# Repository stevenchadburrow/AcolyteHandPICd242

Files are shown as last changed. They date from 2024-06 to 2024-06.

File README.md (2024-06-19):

# AcolyteHandPICd242

This is the Acolyte Hand PIC'd 242, containing two PIC24 microcontrollers:  
The PIC24EP512GP202 and the PIC24FJ128GB202.  
The 'EP does all of the graphics, sound, and button inputs.  
The 'FJ is exclusively designed to be used as a USB host for HID and MSD.

The board is an all through-hole design for easy soldering.

Much of the code will be reused from the Acolyte Hand PIC'd 24 project.

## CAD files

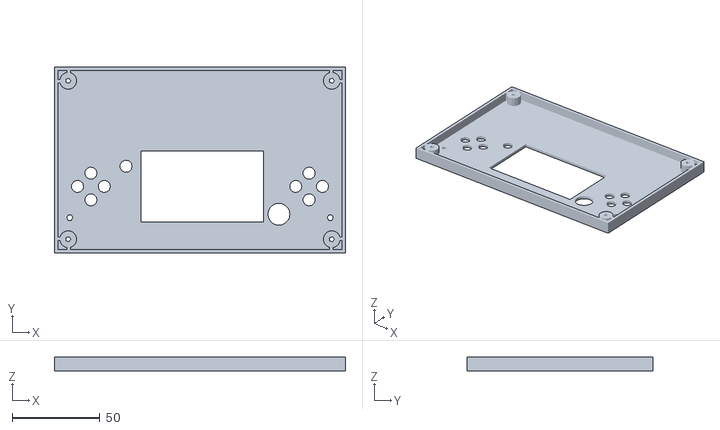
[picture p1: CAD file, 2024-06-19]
HandPICd242-BoxTop.stl
166.0 x 106.0 x 8.00

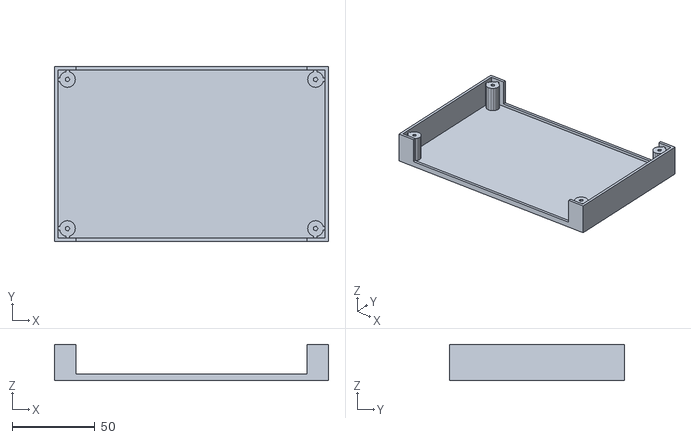
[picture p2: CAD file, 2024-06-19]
HandPICd242-BoxBottom.stl
166.0 x 106.0 x 22.0

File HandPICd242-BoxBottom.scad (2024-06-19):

width = 160;
depth = 100;
tall = 20;
short = 6;
holes = 4.825;

/*
// TOP HALF
translate([0, 0, 0]) {

// bottom
translate([-3, -3, -2]) {
    difference() {
        cube([width+6, depth+6, 2], center = false);
        translate([3+holes, 3+holes, -1]) {
            cylinder(4, 3, 3);
        }
        translate([3+width-holes, 3+holes, -1]) {
            cylinder(4, 3, 3);
        }
        translate([3+width-holes, 3+depth-holes, -1]) {
            cylinder(4, 3, 3);
        }
        translate([3+holes, 3+depth-holes, -1]) {
            cylinder(4, 3, 3);
        }
        translate([3, 3, 0]) {
            translate([46.355,14.605,-1]) {
                cube([70,40.64,4], center = false);
            }
            
            translate([17.78, 27.25, -1]) {
                cylinder(4, 3.5, 3.5);
            }
            translate([10.16, 34.925, -1]) {
                cylinder(4, 3.5, 3.5);
            }
            translate([17.78, 42.49, -1]) {
                cylinder(4, 3.5, 3.5);
            }
            translate([25.4, 34.925, -1]) {
                cylinder(4, 3.5, 3.5);
            }
            
            translate([142.24, 27.25, -1]) {
                cylinder(4, 3.5, 3.5);
            }
            translate([134.62, 34.925, -1]) {
                cylinder(4, 3.5, 3.5);
            }
            translate([142.24, 42.49, -1]) {
                cylinder(4, 3.5, 3.5);
            }
            translate([149.86, 34.925, -1]) {
                cylinder(4, 3.5, 3.5);
            }
            
            translate([37.81, 46.43, -1]) {
                cylinder(4, 3.5, 3.5);
            }
            
            translate([5.715, 17.14, -1]) {
                cylinder(4, 1.75, 1.75);
            }
            translate([154.305, 17.14, -1]) {
                cylinder(4, 1.75, 1.75);
            }
            
            translate([125.02, 19.05, -1]) {
                cylinder(4, 6.25, 6.25);
            }
        }
    }
}

// front
translate([-3, -3, 0]) {
    difference() {
        cube([width+6, 2, short], center = false);
    }
}

// back
translate([-3, depth+1, 0]) {
    difference() {
        cube([width+6, 2, short], center = false);
    }
}

// left
translate([-3, -3, 0]) {
    cube([2, depth+6, short], center = false);
}

// right
translate([width+1, -3, 0]) {
    cube([2, depth+6, short], center = false);
}

// front left corner
translate([holes, holes, 0]) {
    difference() {
        cylinder(short, holes, holes);
        translate([0, 0, -1]) {
            cylinder(short+2, 1.5, 1.5);
        }
    }
}
translate([4, -1, 0]) {
    cube([2, 3, short], center = false);
}
translate([-1, 4, 0]) {
    cube([3, 2, short], center = false);
}

// front right corner
translate([width-holes, holes, 0]) {
    difference() {
        cylinder(short, holes, holes);
        translate([0, 0, -1]) {
            cylinder(short+2, 1.5, 1.5);
        }
    }
}
translate([width-6, -1, 0]) {
    cube([2, 3, short], center = false);
}
translate([width-1, 4, 0]) {
    cube([3, 2, short], center = false);
}

// back right corner
translate([width-holes, depth-holes, 0]) {
    difference() {
        cylinder(short, holes, holes);
        translate([0, 0, -1]) {
            cylinder(short+2, 1.5, 1.5);
        }
    }
}
translate([width-6, depth-1, 0]) {
    cube([2, 3, short], center = false);
}
translate([width-1, depth-6, 0]) {
    cube([3, 2, short], center = false);
}

// back left corner
translate([holes, depth-holes, 0]) {
    difference() {
        cylinder(short, holes, holes);
        translate([0, 0, -1]) {
            cylinder(short+2, 1.5, 1.5);
        }
    }
}
translate([4, depth-1, 0]) {
    cube([2, 3, short], center = false);
}
translate([-1, depth-6, 0]) {
    cube([3, 2, short], center = false);
}      
}
*/


// BOTTOM HALF
//translate([0, 120, 0]) {
translate([0, 0, 0]) {
    
// bottom
translate([-3, -3, -2]) {
    difference() {
        cube([width+6, depth+6, 2], center = false);
        //translate([3+holes, 3+holes, -1]) {
        //    cylinder(4, 3, 3);
        //}
        //translate([3+width-holes, 3+holes, -1]) {
        //    cylinder(4, 3, 3);
        //}
        //translate([3+width-holes, 3+depth-holes, -1]) {
        //    cylinder(4, 3, 3);
        //}
        //translate([3+holes, 3+depth-holes, -1]) {
        //    cylinder(4, 3, 3);
        //}
    }
}

// front
translate([-3, -3, 0]) {
    difference() {
        cube([width+6, 2, tall], center = false);
        translate([13, -0.5, 2]) {
            cube([width-20, 3, tall+1], center = false);
        }
    }
}

// back
translate([-3, depth+1, 0]) {
    difference() {
        cube([width+6, 2, tall], center = false);
        translate([13, -0.5, 2]) {
            cube([width-20, 3, tall+1], center = false);
        }
    }
}

// left
translate([-3, -3, 0]) {
    cube([2, depth+6, tall], center = false);
}

// right
translate([width+1, -3, 0]) {
    cube([2, depth+6, tall], center = false);
}

// front left corner
translate([holes, holes, 0]) {
    difference() {
        cylinder(tall-1.75, holes, holes);
        translate([0, 0, 0]) {
            cylinder(tall, 1.5, 1.5);
        }
    }
}
translate([4, -1, 0]) {
    cube([2, 3, tall-1.75], center = false);
}
translate([-1, 4, 0]) {
    cube([3, 2, tall-1.75], center = false);
}

// front right corner
translate([width-holes, holes, 0]) {
    difference() {
        cylinder(tall-1.75, holes, holes);
        translate([0, 0, 0]) {
            cylinder(tall, 1.5, 1.5);
        }
    }
}
translate([width-6, -1, 0]) {
    cube([2, 3, tall-1.75], center = false);
}
translate([width-1, 4, 0]) {
    cube([3, 2, tall-1.75], center = false);
}

// back right corner
translate([width-holes, depth-holes, 0]) {
    difference() {
        cylinder(tall-1.75, holes, holes);
        translate([0, 0, 0]) {
            cylinder(tall, 1.5, 1.5);
        }
    }
}
translate([width-6, depth-1, 0]) {
    cube([2, 3, tall-1.75], center = false);
}
translate([width-1, depth-6, 0]) {
    cube([3, 2, tall-1.75], center = false);
}

// back left corner
translate([holes, depth-holes, 0]) {
    difference() {
        cylinder(tall-1.75, holes, holes);
        translate([0, 0, 0]) {
            cylinder(tall, 1.5, 1.5);
        }
    }
}
translate([4, depth-1, 0]) {
    cube([2, 3, tall-1.75], center = false);
}
translate([-1, depth-6, 0]) {
    cube([3, 2, tall-1.75], center = false);
}
}

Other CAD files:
HandPICd242-BoxTop.scad

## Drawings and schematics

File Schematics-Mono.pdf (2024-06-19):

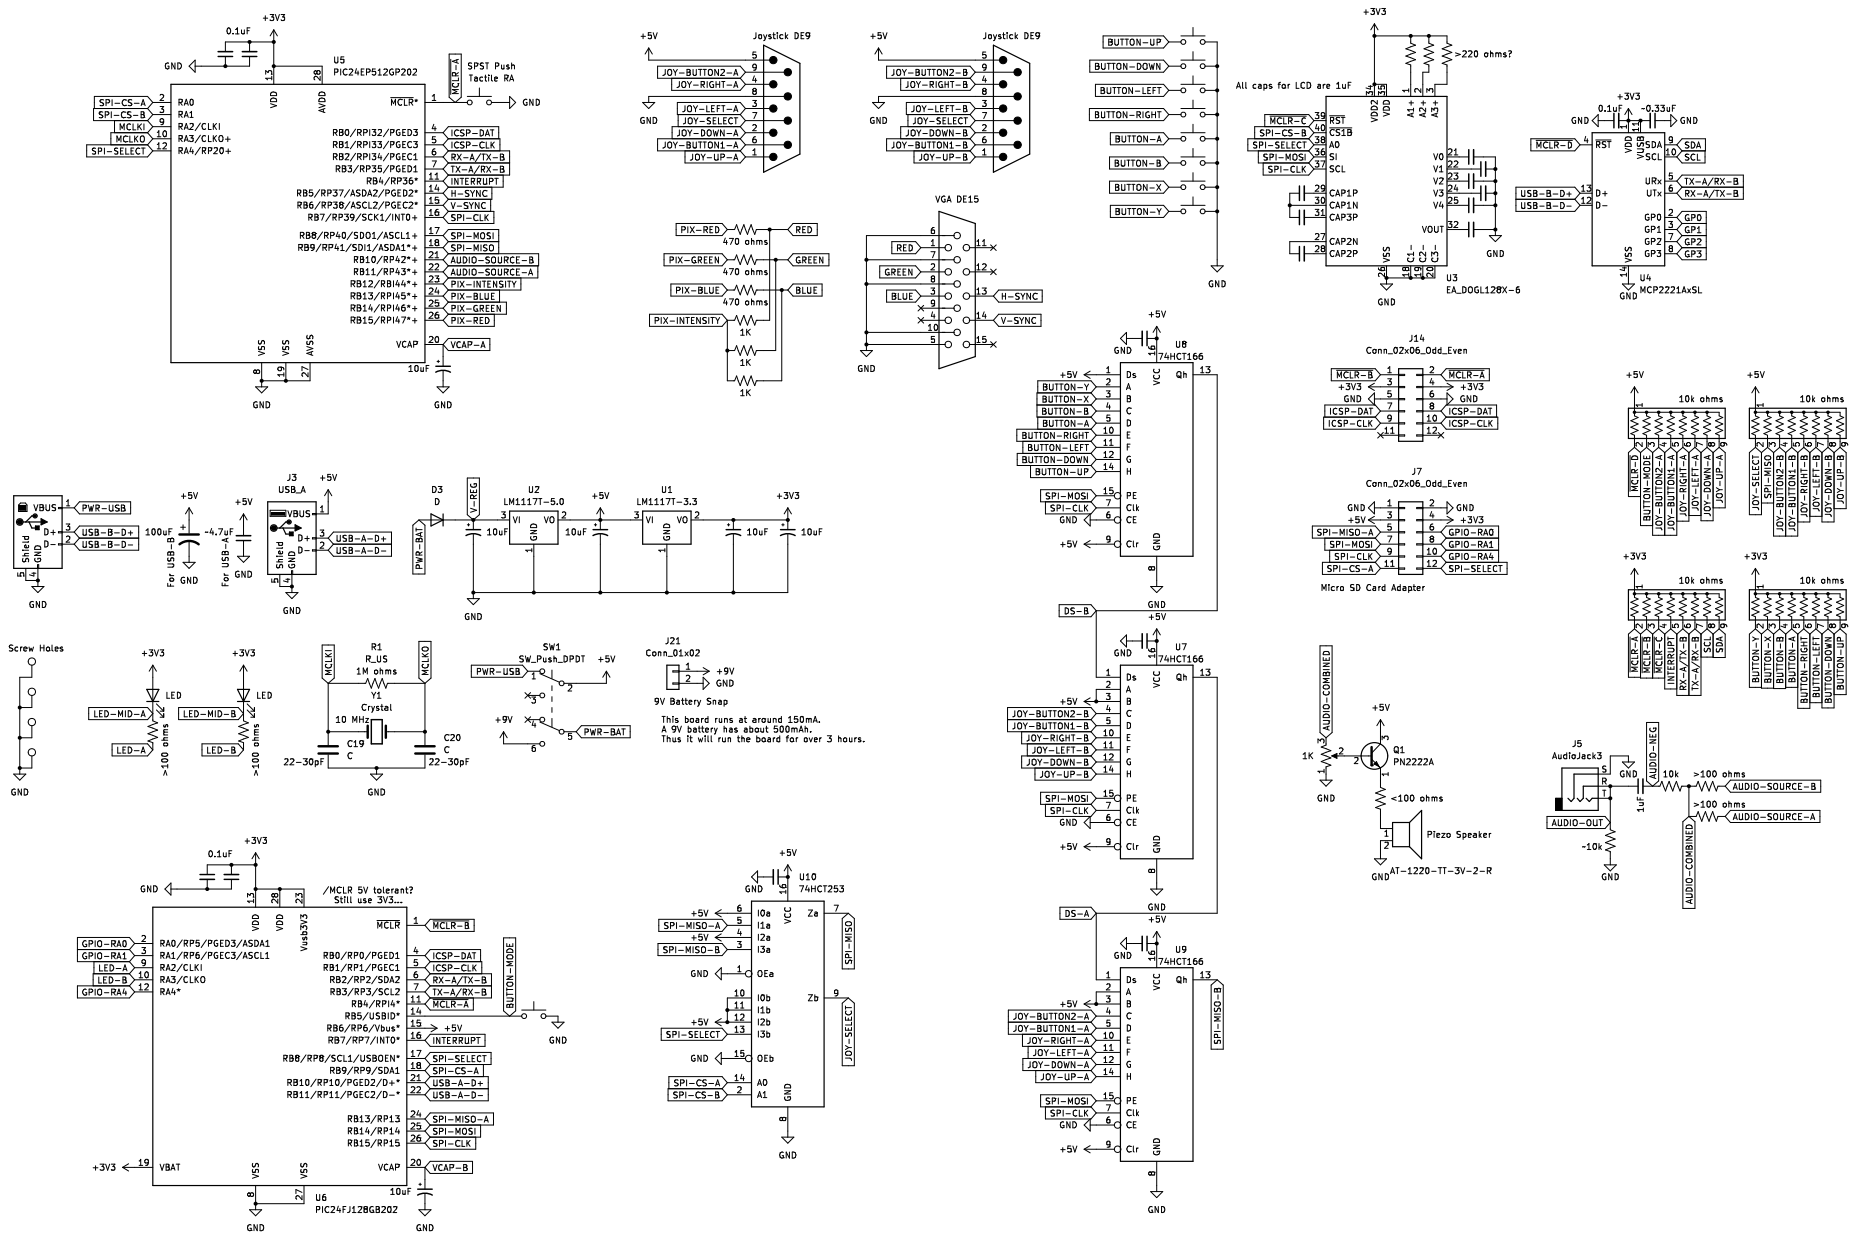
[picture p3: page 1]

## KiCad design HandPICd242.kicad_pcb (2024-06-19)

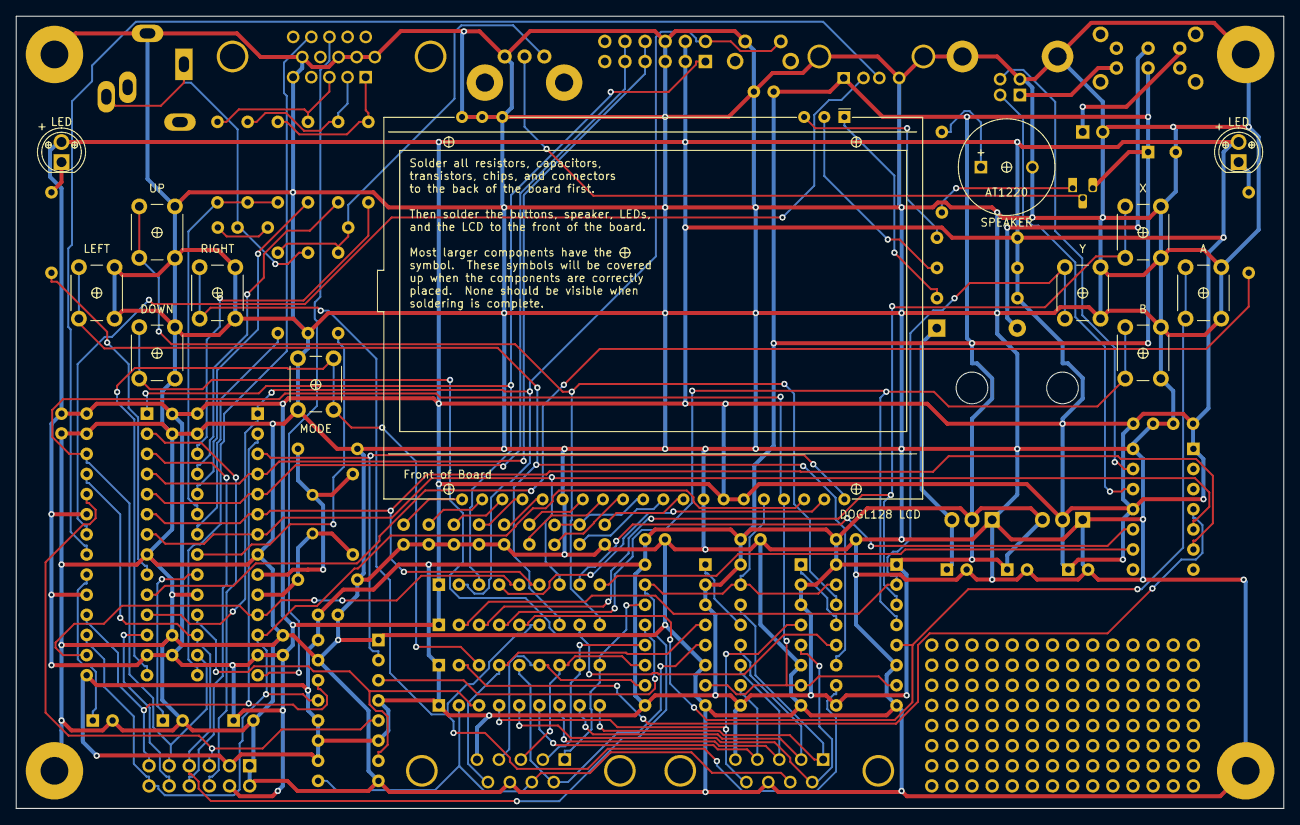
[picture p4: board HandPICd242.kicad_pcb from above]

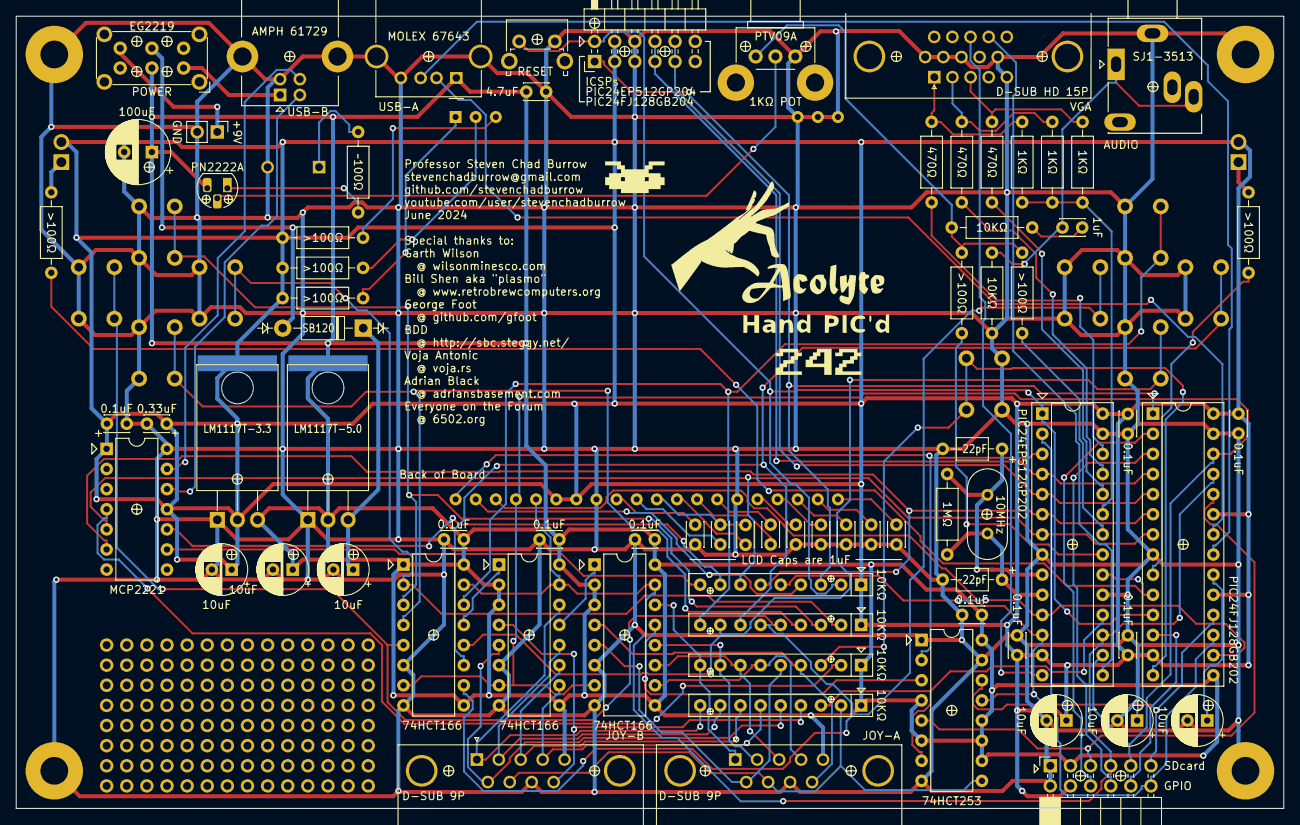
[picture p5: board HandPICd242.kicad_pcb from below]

Board: 2 copper layers, 160.0 x 100.0 mm, 101 parts (84 on the bottom side), 96 nets.

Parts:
C1, C2, C3, C6, C10, C13, C14, C16, C17, C18, C21, C22, C23, C24, C25, C26, C27, C28, C29, C30, C31: C_Small; C_Disc_D3.0mm_W2.0mm_P2.50mm
C4, C7, C8, C9, C12, C15: C_Polarized_Small_US; CP_Radial_D6.3mm_P2.50mm
C5: C_Polarized_US; CP_Radial_D8.0mm_P3.50mm
C19, C20: C; C_Axial_L3.8mm_D2.6mm_P7.50mm_Horizontal
D1, D2: LED; CustomLED
D3: D; D_DO-41_SOD81_P10.16mm_Horizontal
G101: LOGO; AcolyteTitle
G102: LOGO; HandPickedTitle
G103: LOGO; Mystery
G105: LOGO; ModelNum
G106: LOGO; HandPinching
J1: USB_B; USB_B_Lumberg_2411_02_Horizontal
J3: USB_A; USB_A_Molex_67643_Horizontal
J4, J19: DE9_Plug; DSUB-9_Male_Horizontal_P2.77x2.84mm_EdgePinOffset7.70mm_Hou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
J5: AudioJack3; BIGJack_3.5mm_Ledino_KB3SPRS_Horizontal
J6: DE15_Receptacle_HighDensity; DSUB-15-HD_Female_Horizontal_P2.29x2.54mm_VGA
J7: Conn_02x06_Odd_Even; PinSocket_2x06_P2.54mm_Horizontal
J9, J11, J12, J13: Conn_02x14_Odd_Even; BLANK-PinHeader_2x14_P2.54mm_Vertical
J14: Conn_02x06_Odd_Even; PinHeader_2x06_P2.54mm_Horizontal
J21: Conn_01x02; PinHeader_1x02_P2.54mm_Vertical
LS1: Speaker; MagneticBuzzer_ProSignal_ABT-410-RC
Q1: PN2222A; TO-92_HandSolder
R1, R2, R3, R4, R6, R7, R8, R9, R10, R11, R12, R13, R14, R15, R16, R18, R19: R_US; R_Axial_DIN0207_L6.3mm_D2.5mm_P10.16mm_Horizontal
RN1, RN2, RN3, RN4: R_Network08_US; R_Array_SIP9
RV1: R_Potentiometer_US; Potentiometer_Bourns_PTV09A-2_Single_Horizontal
SW1: SW_Push_DPDT; SW_E-Switch_EG2219_DPDT_Angled
SW3, SW4, SW5, SW6, SW7, SW8, SW9, SW10, SW13: SW_Push; SW_PUSH_6mm_H5mm
SW11: SW_Push; SW_Tactile_SPST_Angled_PTS645Vx83-2LFS
TP2, TP3, TP4, TP5: TestPoint; ScrewHole-4-40
U1: LM1117T-3.3; TO-220-3_Horizontal_TabDown-custom
U2: LM1117T-5.0; TO-220-3_Horizontal_TabDown-custom
U3: EA_DOGL128X-6; EA_DOGL128-6
U4: MCP2221AxSL; DIP-14_W7.62mm
U5: PIC24EP512GP202; DIP-28_W7.62mm_Socket
U6: PIC24FJ128GB202; DIP-28_W7.62mm_Socket
U7, U8, U9: 74HCT166; DIP-16_W7.62mm
U10: 74HCT253; DIP-16_W7.62mm
Y1: Crystal; Crystal_HC49-4H_Vertical

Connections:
+3V3: C1.1, C2.2, C3.2, C8.1, C12.1, C13.2, C14.2, C18.2, D1.2 (A), D2.2 (A), J7.4, J14.3, J14.4, R6.1, R18.1, R19.1, RN2.1 (common), RN4.1 (common), U1.2 (VO), U3.34 (VDD2), U3.35 (VDD), U4.1 (VDD), U4.11 (VUSB), U5.13 (VDD), U5.28 (AVDD), U6.13 (VDD), U6.19 (VBAT), U6.23 (Vusb3V3), U6.28 (VDD)
+5V: C5.1, C6.2, C15.1, C16.1, C17.1, C30.1, C31.1, J3.1 (VBUS), J4.5, J7.3, J19.5, Q1.3 (C), RN1.1 (common), RN3.1 (common), SW1.2 (B), U1.3 (VI), U2.2 (VO), U6.15 (RB6/RP6/Vbus*), U7.2 (A), U7.3 (B), U7.9 (Clr), U7.16 (VCC), U8.1 (Ds), U8.9 (Clr), U8.16 (VCC), U9.2 (A), U9.3 (B), U9.9 (Clr), U9.16 (VCC), U10.4 (I2a), U10.6 (I0a), U10.10 (I0b), U10.11 (I1b), U10.12 (I2b), U10.16 (VCC)
+9V: J21.1, SW1.6 (C)
AUDIO-COMBINED: R8.2, R9.1, R10.1, RV1.3
AUDIO-NEG: C10.2, R8.1
AUDIO-OUT: C10.1, J5.R, J5.T, R7.2
AUDIO-SOURCE-A: R10.2, U5.22 (RB11/RP43*+)
AUDIO-SOURCE-B: R9.2, U5.21 (RB10/RP42*+)
BLUE: J6.3, R13.2, R16.2
BUTTON-A: RN4.5 (R4), SW7.1, U8.5 (D)
BUTTON-B: RN4.4 (R3), SW8.1, U8.4 (C)
BUTTON-DOWN: RN4.8 (R7), SW4.1, U8.12 (G)
BUTTON-LEFT: RN4.7 (R6), SW5.1, U8.11 (F)
BUTTON-MODE: RN1.3 (R2), SW13.1, U6.14 (RB5/USBID*)
BUTTON-RIGHT: RN4.6 (R5), SW6.1, U8.10 (E)
BUTTON-UP: RN4.9 (R8), SW3.1, U8.14 (H)
BUTTON-X: RN4.3 (R2), SW9.1, U8.3 (B)
BUTTON-Y: RN4.2 (R1), SW10.1, U8.2 (A)
DS-A: U7.13 (Qh), U9.1 (Ds)
DS-B: U7.1 (Ds), U8.13 (Qh)
GND: C1.2, C2.1, C3.1, C4.2, C5.2, C6.1, C7.2, C8.2, C9.2, C12.2, C13.1, C14.1, C15.2, C16.2, C17.2, C18.1, C19.2, C20.2, C24.2, C25.2, C26.2, C27.2, C28.2, C29.2, C30.2, C31.2, J1.4 (GND), J1.5 (Shield), J3.4 (GND), J3.5 (Shield), J4.8, J5.S, J6.5, J6.6, J6.7, J6.8, J6.10, J7.1, J7.2, J14.5, J14.6, J19.8, J21.2, LS1.2, R7.1, RV1.1, SW3.2, SW4.2, SW5.2, SW6.2, SW7.2, SW8.2, SW9.2, SW10.2, SW11.2, SW13.2, TP2.1, TP3.1, TP4.1, TP5.1, U1.1 (GND), U2.1 (GND), U3.18 (C1-), U3.19 (C2-), U3.20 (C3-), U3.26 (VSS), U3.33 (VSS), U4.14 (VSS), U5.8 (VSS), U5.19 (VSS), U5.27 (AVSS), U6.8 (VSS), U6.27 (VSS), U7.6 (CE), U7.8 (GND), U8.6 (CE), U8.8 (GND), U9.6 (CE), U9.8 (GND), U10.1 (OEa), U10.8 (GND), U10.15 (OEb)
GPIO-RA0: J7.6, U6.2 (RA0/RP5/PGED3/ASDA1)
GPIO-RA1: J7.8, U6.3 (RA1/RP6/PGEC3/ASCL1)
GPIO-RA4: J7.10, U6.12 (RA4*)
GREEN: J6.2, R12.2, R15.2
H-SYNC: J6.13, U5.14 (RB5/RP37/ASDA2/PGED2*)
ICSP-CLK: J14.9, J14.10, U5.5 (RB1/RPI33/PGEC3), U6.5 (RB1/RP1/PGEC1)
ICSP-DAT: J14.7, J14.8, U5.4 (RB0/RPI32/PGED3), U6.4 (RB0/RP0/PGED1)
INTERRUPT: RN2.5 (R4), U5.11 (RB4/RP36*), U6.16 (RB7/RP7/INT0*)
JOY-BUTTON1-A: J4.6, RN1.5 (R4), U9.5 (D)
JOY-BUTTON1-B: J19.6, RN3.5 (R4), U7.5 (D)
JOY-BUTTON2-A: J4.9, RN1.4 (R3), U9.4 (C)
JOY-BUTTON2-B: J19.9, RN3.4 (R3), U7.4 (C)
JOY-DOWN-A: J4.2, RN1.8 (R7), U9.12 (G)
JOY-DOWN-B: J19.2, RN3.8 (R7), U7.12 (G)
JOY-LEFT-A: J4.3, RN1.7 (R6), U9.11 (F)
JOY-LEFT-B: J19.3, RN3.7 (R6), U7.11 (F)
JOY-RIGHT-A: J4.4, RN1.6 (R5), U9.10 (E)
JOY-RIGHT-B: J19.4, RN3.6 (R5), U7.10 (E)
JOY-SELECT: J4.7, J19.7, RN3.2 (R1), U10.9 (Zb)
JOY-UP-A: J4.1, RN1.9 (R8), U9.14 (H)
JOY-UP-B: J19.1, RN3.9 (R8), U7.14 (H)
LED-A: R3.2, U6.9 (RA2/CLKI)
LED-B: R2.2, U6.10 (RA3/CLKO)
LED-MID-A: D1.1 (K), R3.1
LED-MID-B: D2.1 (K), R2.1
MCLKI: C19.1, R1.1, U5.9 (RA2/CLKI), Y1.1
MCLKO: C20.1, R1.2, U5.10 (RA3/CLKO+), Y1.2
unnamed: LS1.1, R4.2
unnamed: Q1.2 (B), RV1.2
unnamed: Q1.1 (E), R4.1
unnamed: R6.2, U3.1 (A1+)
unnamed: R18.2, U3.2 (A2+)
unnamed: R19.2, U3.3 (A3+)
unnamed: C21.1, C22.1, U3.30 (CAP1N)
unnamed: C22.2, U3.29 (CAP1P)
unnamed: C23.1, U3.27 (CAP2N)
unnamed: C23.2, U3.28 (CAP2P)
unnamed: C21.2, U3.31 (CAP3P)
unnamed: C24.1, U3.21 (V0)
unnamed: C25.1, U3.22 (V1)
unnamed: C26.1, U3.23 (V2)
unnamed: C27.1, U3.24 (V3)
unnamed: C28.1, U3.25 (V4)
unnamed: C29.1, U3.32 (VOUT)
PIX-BLUE: R13.1, U5.24 (RB13/RPI45*+)
PIX-GREEN: R12.1, U5.25 (RB14/RPI46*+)
PIX-INTENSITY: R14.1, R15.1, R16.1, U5.23 (RB12/RBI44*+)
PIX-RED: R11.1, U5.26 (RB15/RPI47*+)
PWR-BAT: D3.2 (A), SW1.5 (B)
PWR-USB: J1.1 (VBUS), SW1.1 (A)
RED: J6.1, R11.2, R14.2
RX-A/TX-B: RN2.6 (R5), U4.6 (UTx), U5.6 (RB2/RPI34/PGEC1), U6.6 (RB2/RP2/SDA2)
SCL: RN2.8 (R7), U4.10 (SCL)
SDA: RN2.9 (R8), U4.9 (SDA)
SPI-CLK: J7.9, U3.37 (SCL), U5.16 (RB7/RP39/SCK1/INT0+), U6.26 (RB15/RP15), U7.7 (Clk), U8.7 (Clk), U9.7 (Clk)
SPI-CS-A: J7.11, U5.2 (RA0), U6.18 (RB9/RP9/SDA1), U10.14 (A0)
SPI-CS-B: U3.40 (~CS1B), U5.3 (RA1), U10.2 (A1)
SPI-MISO: RN3.3 (R2), U5.18 (RB9/RP41/SDI1/ASDA1*+), U10.7 (Za)
SPI-MISO-A: J7.5, U6.24 (RB13/RP13), U10.5 (I1a)
SPI-MISO-B: U9.13 (Qh), U10.3 (I3a)
SPI-MOSI: J7.7, U3.36 (SI), U5.17 (RB8/RP40/SDO1/ASCL1+), U6.25 (RB14/RP14), U7.15 (PE), U8.15 (PE), U9.15 (PE)
SPI-SELECT: J7.12, U3.38 (A0), U5.12 (RA4/RP20+), U6.17 (RB8/RP8/SCL1/USBOEN*), U10.13 (I3b)
TX-A/RX-B: RN2.7 (R6), U4.5 (URx), U5.7 (RB3/RP35/PGED1), U6.7 (RB3/RP3/SCL2)
USB-A-D+: J3.3 (D+), U6.21 (RB10/RP10/PGED2/D+*)
USB-A-D-: J3.2 (D-), U6.22 (RB11/RP11/PGEC2/D-*)
USB-B-D+: J1.3 (D+), U4.13 (D+)
USB-B-D-: J1.2 (D-), U4.12 (D-)
V-REG: C4.1, D3.1 (K), U2.3 (VI)
V-SYNC: J6.14, U5.15 (RB6/RP38/ASCL2/PGEC2*)
VCAP-A: C7.1, U5.20 (VCAP)
VCAP-B: C9.1, U6.20 (VCAP)
~MCLR-A: J14.2, RN2.2 (R1), SW11.1, U5.1 (~MCLR*), U6.11 (RB4/RPI4*)
~MCLR-B: J14.1, RN2.3 (R2), U6.1 (~MCLR)
~MCLR-C: RN2.4 (R3), U3.39 (~RST)
~MCLR-D: RN1.2 (R1), U4.4 (~RST)
